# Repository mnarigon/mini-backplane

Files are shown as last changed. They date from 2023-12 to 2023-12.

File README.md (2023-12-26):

## A 4-slot S-100 bus mini-backplane with power supply chassis.

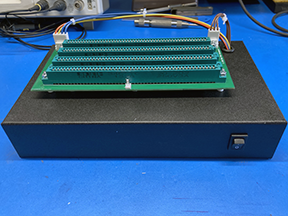
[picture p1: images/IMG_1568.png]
completed chassis


#### Description

This is a 4-slot S-100 bus mini-backplane with power supply chassis.

It is intended for someone interested in building and running S-100 bus cards, possibly as a first project or for use on a test bench.

Features:
- 4 slots.
- Chassis is designed for three Mean Well switching power supplies to provide 8V, 16V, and -16V in one unit. The maximum 8V current is 10 amps.
- Jumpers to ground for S-100 pins 20, 53, and 70. Some pre-IEEE-696 cards use these pins for signals where IEEE-696 defines these pins as grounds.
- Connector for a reset switch.

#### Mini-backplane Design Files

The mini-backplane design files in KiCad 7 are in the kicad directory.

The generated mini-backplane Gerber and drill files are in the file mini-backplane-gerbers.zip.

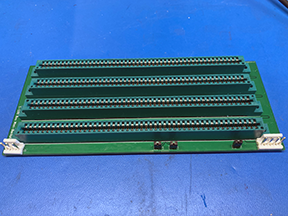
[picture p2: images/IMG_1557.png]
mini-backplane board


#### Chassis Design Files

The bill of materials is in the bom directory.

There is a poorly-executed layout drawing for the chassis holes in the chassis directory.

At maximum output power the power supplies will dissipate ~10W. A simple thermal
analysis indicated that cooling would be OK without any holes in the chassis.
However, I have a friend with a CNC mill who was willing mill the chassis, so I
added the cooling slots as shown on the drawing.

#### Chassis Assembly Notes

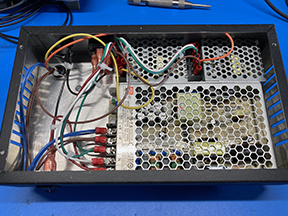
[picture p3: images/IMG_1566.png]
chassis wiring


The chassis is tight, if I built this again I would select a slightly larger chassis. The height is OK, but a chassis that was an inch or two longer and wider would make it easier to wire and install the power supplies.

The power switch didn’t sit tight in its mounting hole. The chassis wall thickness is 0.040 inch and the switch might have been designed for a thicker walled chassis. I used some hot glue on the switch to keep it from moving.

Wait to install the IEC power connector until you have the power supplies installed. You will need clearance to install the 16V and -16V power supplies.

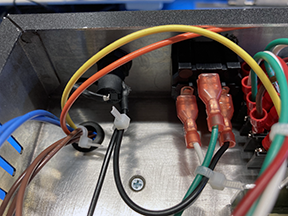
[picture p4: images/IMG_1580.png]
IEC power connector


#### Assembly Steps

1. Make up the wires that will go to the IEC power connector quick connect terminals.
1. Make up the wires that go from the backplane connectors to the power supplies.
1. Wire the 16V and -16V power supplies to each other and the backplane cables.
1. Wire the fuse holder and power switch.
1. Epoxy two of the 4-40 by 1 inch flat-headed screws that hold the mini-backplane to the chassis. They will be hidden by the installed power supplies.
1. Mount the 8V supply and wire to the switch and IEC connector wires.
1. Mount the 16V and -16V supplies. They will fit in but it will take some persuasion.
1. Install the IEC power connector. Finish installing all the wiring.
1. Complete by mounting the backplane on the chassis.

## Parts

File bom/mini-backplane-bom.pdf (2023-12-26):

Mini-Backplane BOM

Designator | Part | Value | Footprint | Manufacturer | Quantity | Digikey Part Number | Unit Price | Total
J1 | Header, Male Pins | | AMP_640445-4 | | 1 | A1972-ND | $0.27 | $0.27
J2 | Header, Male Pins | | AMP_640445-3 | | 1 | A19890-ND | $0.26 | $0.26
J3 | Header, Male Pins | | AMP_640454-2 | | 1 | A19423-ND | $0.15 | $0.15
JP1-JP3 | Pin Header | | PinHeader_01x02_P2.54mm | | 3 | 609-3507-ND | $0.16 | $0.48
| Mating Connector for J1 | | | | 1 | A24113-ND | $0.25 | $0.25
| Mating Connector for J2 | | | | 1 | A24112-ND | $0.20 | $0.20
| Mating Connector for J3 | | | | 1 | A99613-ND | $0.15 | $0.15
| Contacts for J1, J2 | | | | 7 | A31396-ND | $0.35 | $2.45
| Contacts for J3 | | | | 2 | A100453CT-ND | $0.10 | $0.20
| Shunts for JP1-JP3 | | | | 3 | S9000-ND | $0.10 | $0.30
P1-P4 | Card Edge Connector | | EDAC_346-100-520-202 | | 4 | EDC346102-ND or ESA50DRSH-S288-ND | $15.48 | $61.92
| Chassis | | 10*6*2in (L*W*H) | Hammond 1444-16 | 1 | HM264-ND | $20.48 | $20.48
| Cover | | 10*6in (L*W*H) | Hammond 1434-16 | 1 | HM280-ND | $11.00 | $11.00
| 8V Power Supply | | 159*97*30mm (L*W*H) | Mean Well RSP 75-7.5 | 1 | 1866-4289-ND | $36.93 | $36.93
| +16V and -16V Power Supplies | | 62.5*51*28mm (L*W*H) | Mean Well RS-15-15 | 2 | 1866-4129-ND | $10.86 | $21.72
| Fuse Holder 10 A 250V 1 Circuit Cartridge Panel Mount | | | Wurth | 1 | 732-11380-ND | $1.86 | $1.86
| Fuse 1.25A 250V 5x20mm Slo-blow | | | Bel Fuse | 1 | 507-1247-ND | $0.25 | $0.25
| Rocker Switch SPST 10A (AC) 125 V Panel Mount, Snap-In | | | E-Switch | 1 | EG5617-ND | $0.66 | $0.66
| Power Entry, IEC Appliance, 10A | | | DIT | 1 | 4761-DAC-12F-ND | $0.73 | $0.73
| Grommet, 0.375in, Rubber, Black | | | Keystone Electronics | 1 | 36-745-ND | $0.27 | $0.27
| Spade Connector, 18-22AWG, M3 (for +8V PS) | | | | 10 | A135212-ND | $0.45 | $4.50
| Spade Connector, 18-22AWG, M3 (for +/-16V PS) | | | | 14 | 298-20471-1-ND | $0.42 | $5.87
| Quick-Connect Connector, 4.7mm | | | | 5 | A27806CT-ND | $0.26 | $1.30
| Bumper Cylindrical, Recessed Center 0.500" Dia | | | Keystone Electronics | 4 | 36-720-ND | $0.32 | $1.28
| Round Spacer #4 Nylon, 3/8in | | | Bivar, Inc. | 4 | 492-1091-ND | $0.10 | $0.40
| 6-32xL3/8 in Self-Tapping Sheet Metal Screws (for cover) | | | Bolt Depot | 4
| 4-40xL1/2 in Pan Head Machine Screw (for bumper feet) | | | Bolt Depot | 4
| #4 washer (for bumper feet) | | | Bolt Depot | 4
| 4-40 nut (for bumper feet, double to lock) | | | Bolt Depot | 8
| 4-40xL1 in Flat Head Machine Screw (for standoffs) | | | Bolt Depot | 4
| 4-40 K-nut (for standoffs) | | | Bolt Depot | 4
| M3xL5 Hardware (for PS mount) | | | Bolt Depot | 6
| M3 washer (for PS mount) | | | Bolt Depot | 6
| M3 lock washer (for PS mount) | | | Bolt Depot | 6
| Black/White/Green/Red/Brown/Blue/Orange/Yellow 18-Gauge Wire
Total | | | | | | | | $173.88

1

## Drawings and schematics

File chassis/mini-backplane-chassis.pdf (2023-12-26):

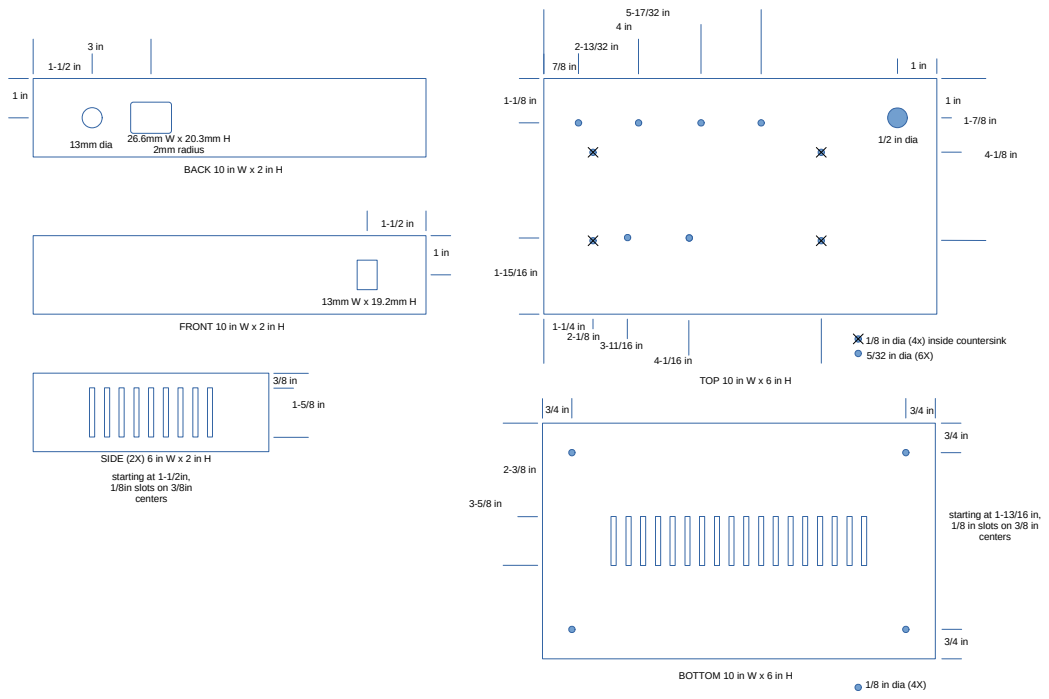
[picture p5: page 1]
26.6mm W x 20.3mm H 2mm radius 13mm dia; 1/2 in dia; 1/8 in dia (4X)

BACK 10 in W x 2 in H

FRONT 10 in W x 2 in H

1/8 in dia (4x) inside countersink
5/32 in dia (6X)

TOP 10 in W x 6 in H

SIDE (2X) 6 in W x 2 in H
starting at 1-1/2in,
1/8in slots on 3/8in
centers

starting at 1-13/16 in,
1/8 in slots on 3/8 in

BOTTOM 10 in W x 6 in H

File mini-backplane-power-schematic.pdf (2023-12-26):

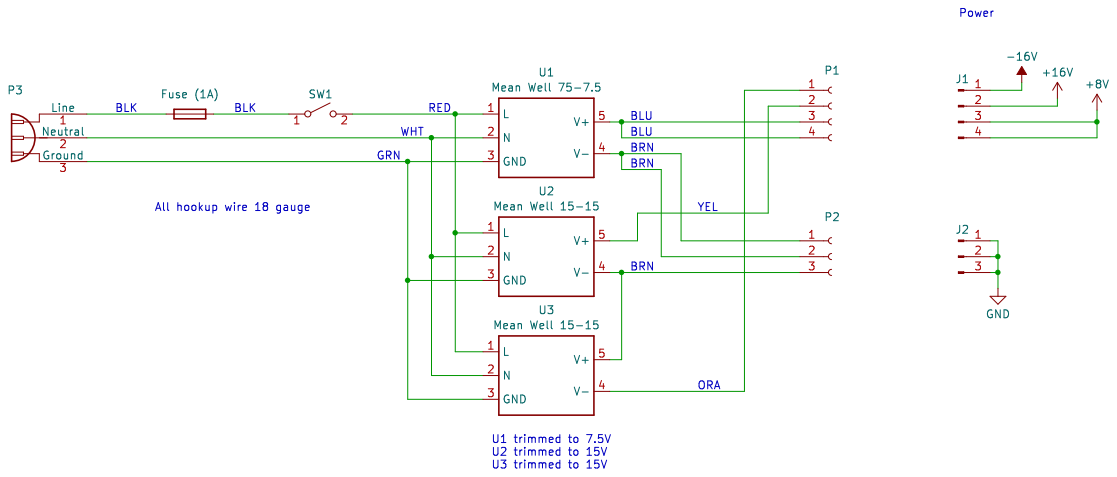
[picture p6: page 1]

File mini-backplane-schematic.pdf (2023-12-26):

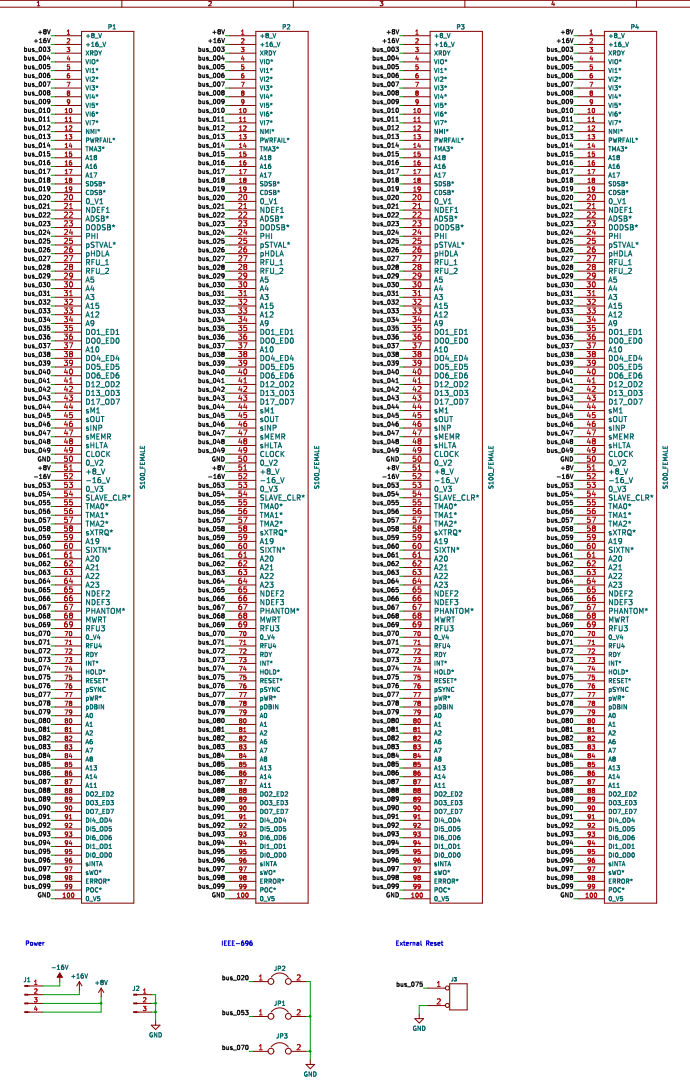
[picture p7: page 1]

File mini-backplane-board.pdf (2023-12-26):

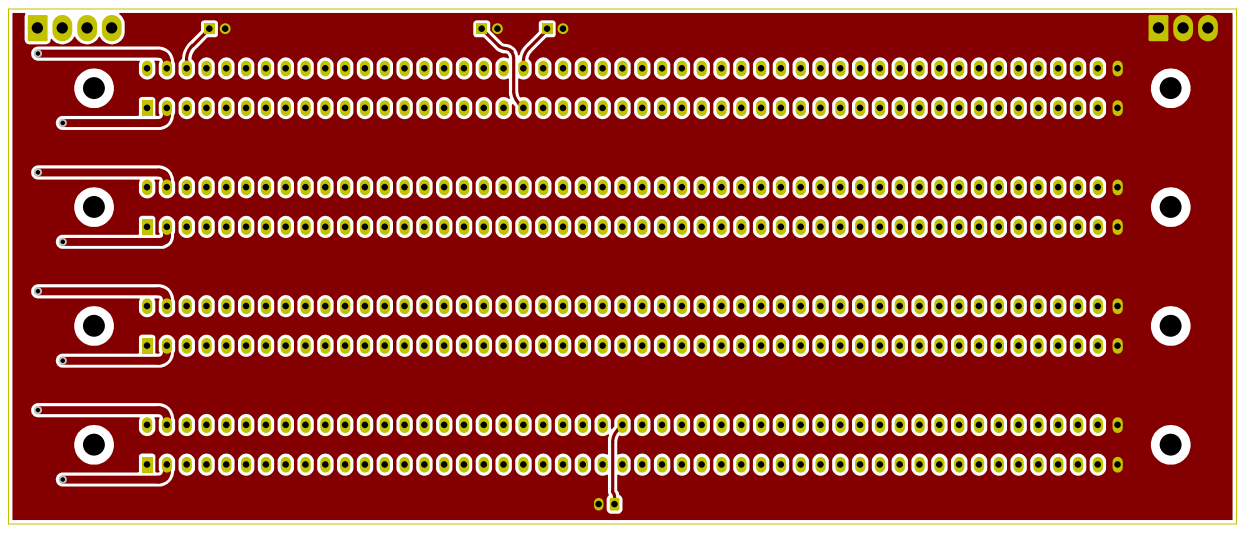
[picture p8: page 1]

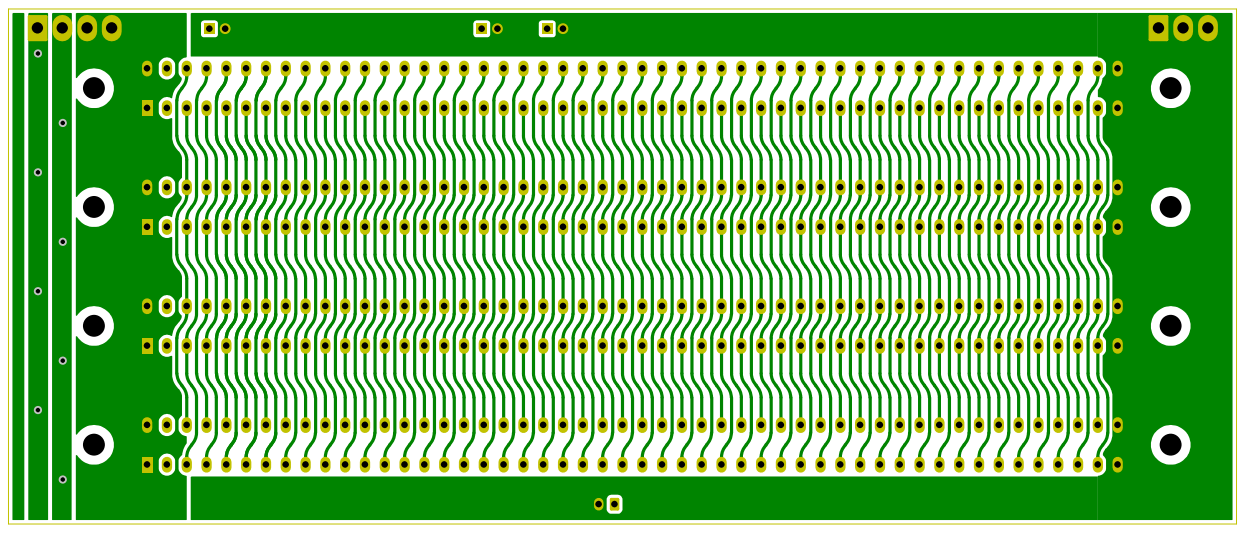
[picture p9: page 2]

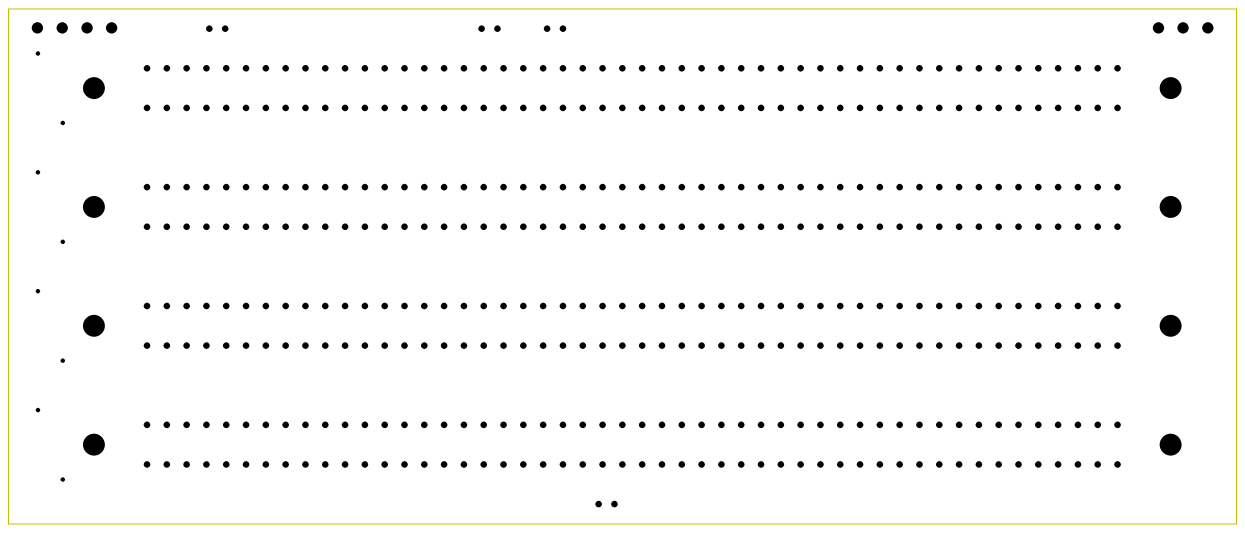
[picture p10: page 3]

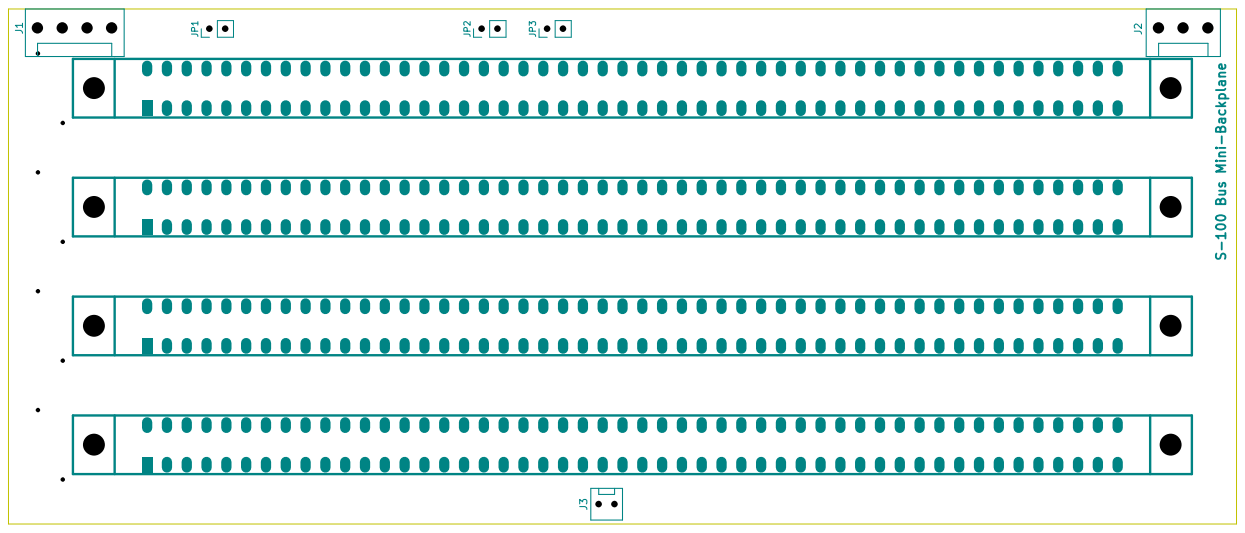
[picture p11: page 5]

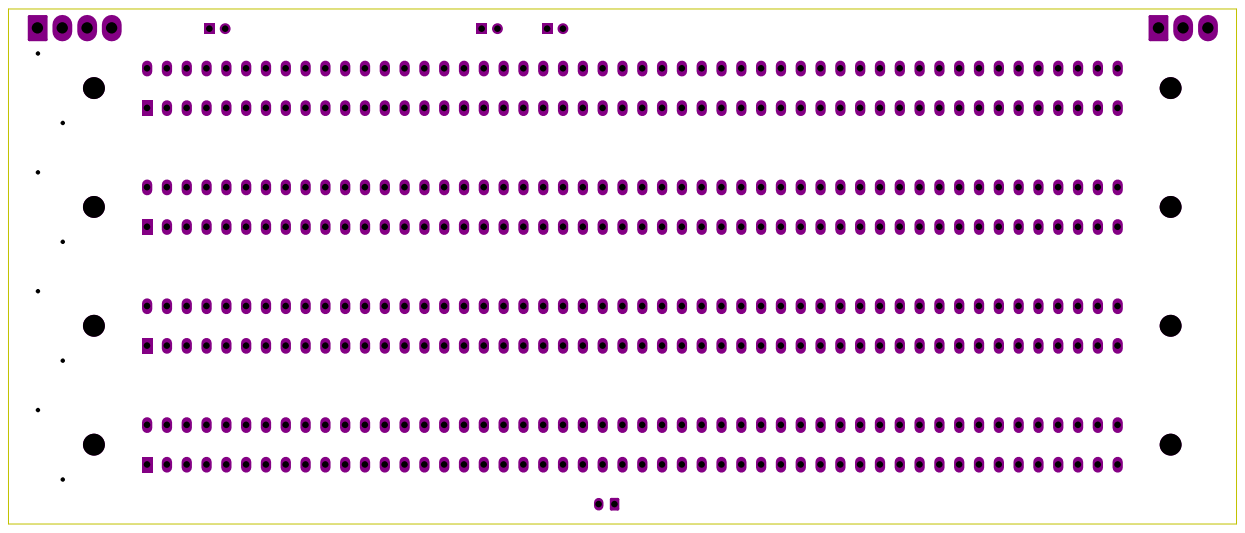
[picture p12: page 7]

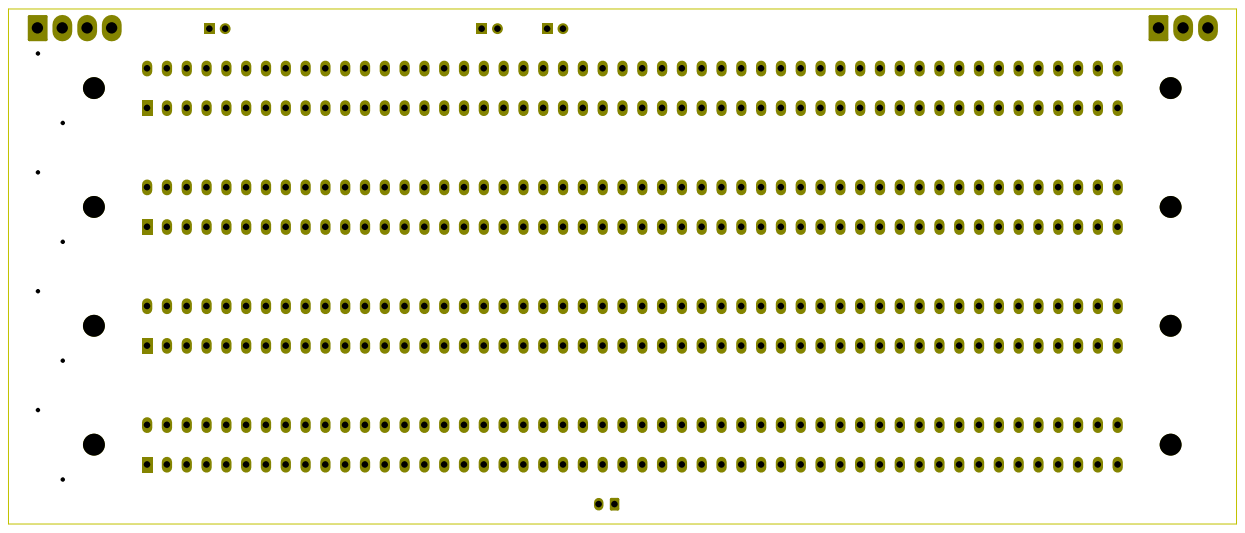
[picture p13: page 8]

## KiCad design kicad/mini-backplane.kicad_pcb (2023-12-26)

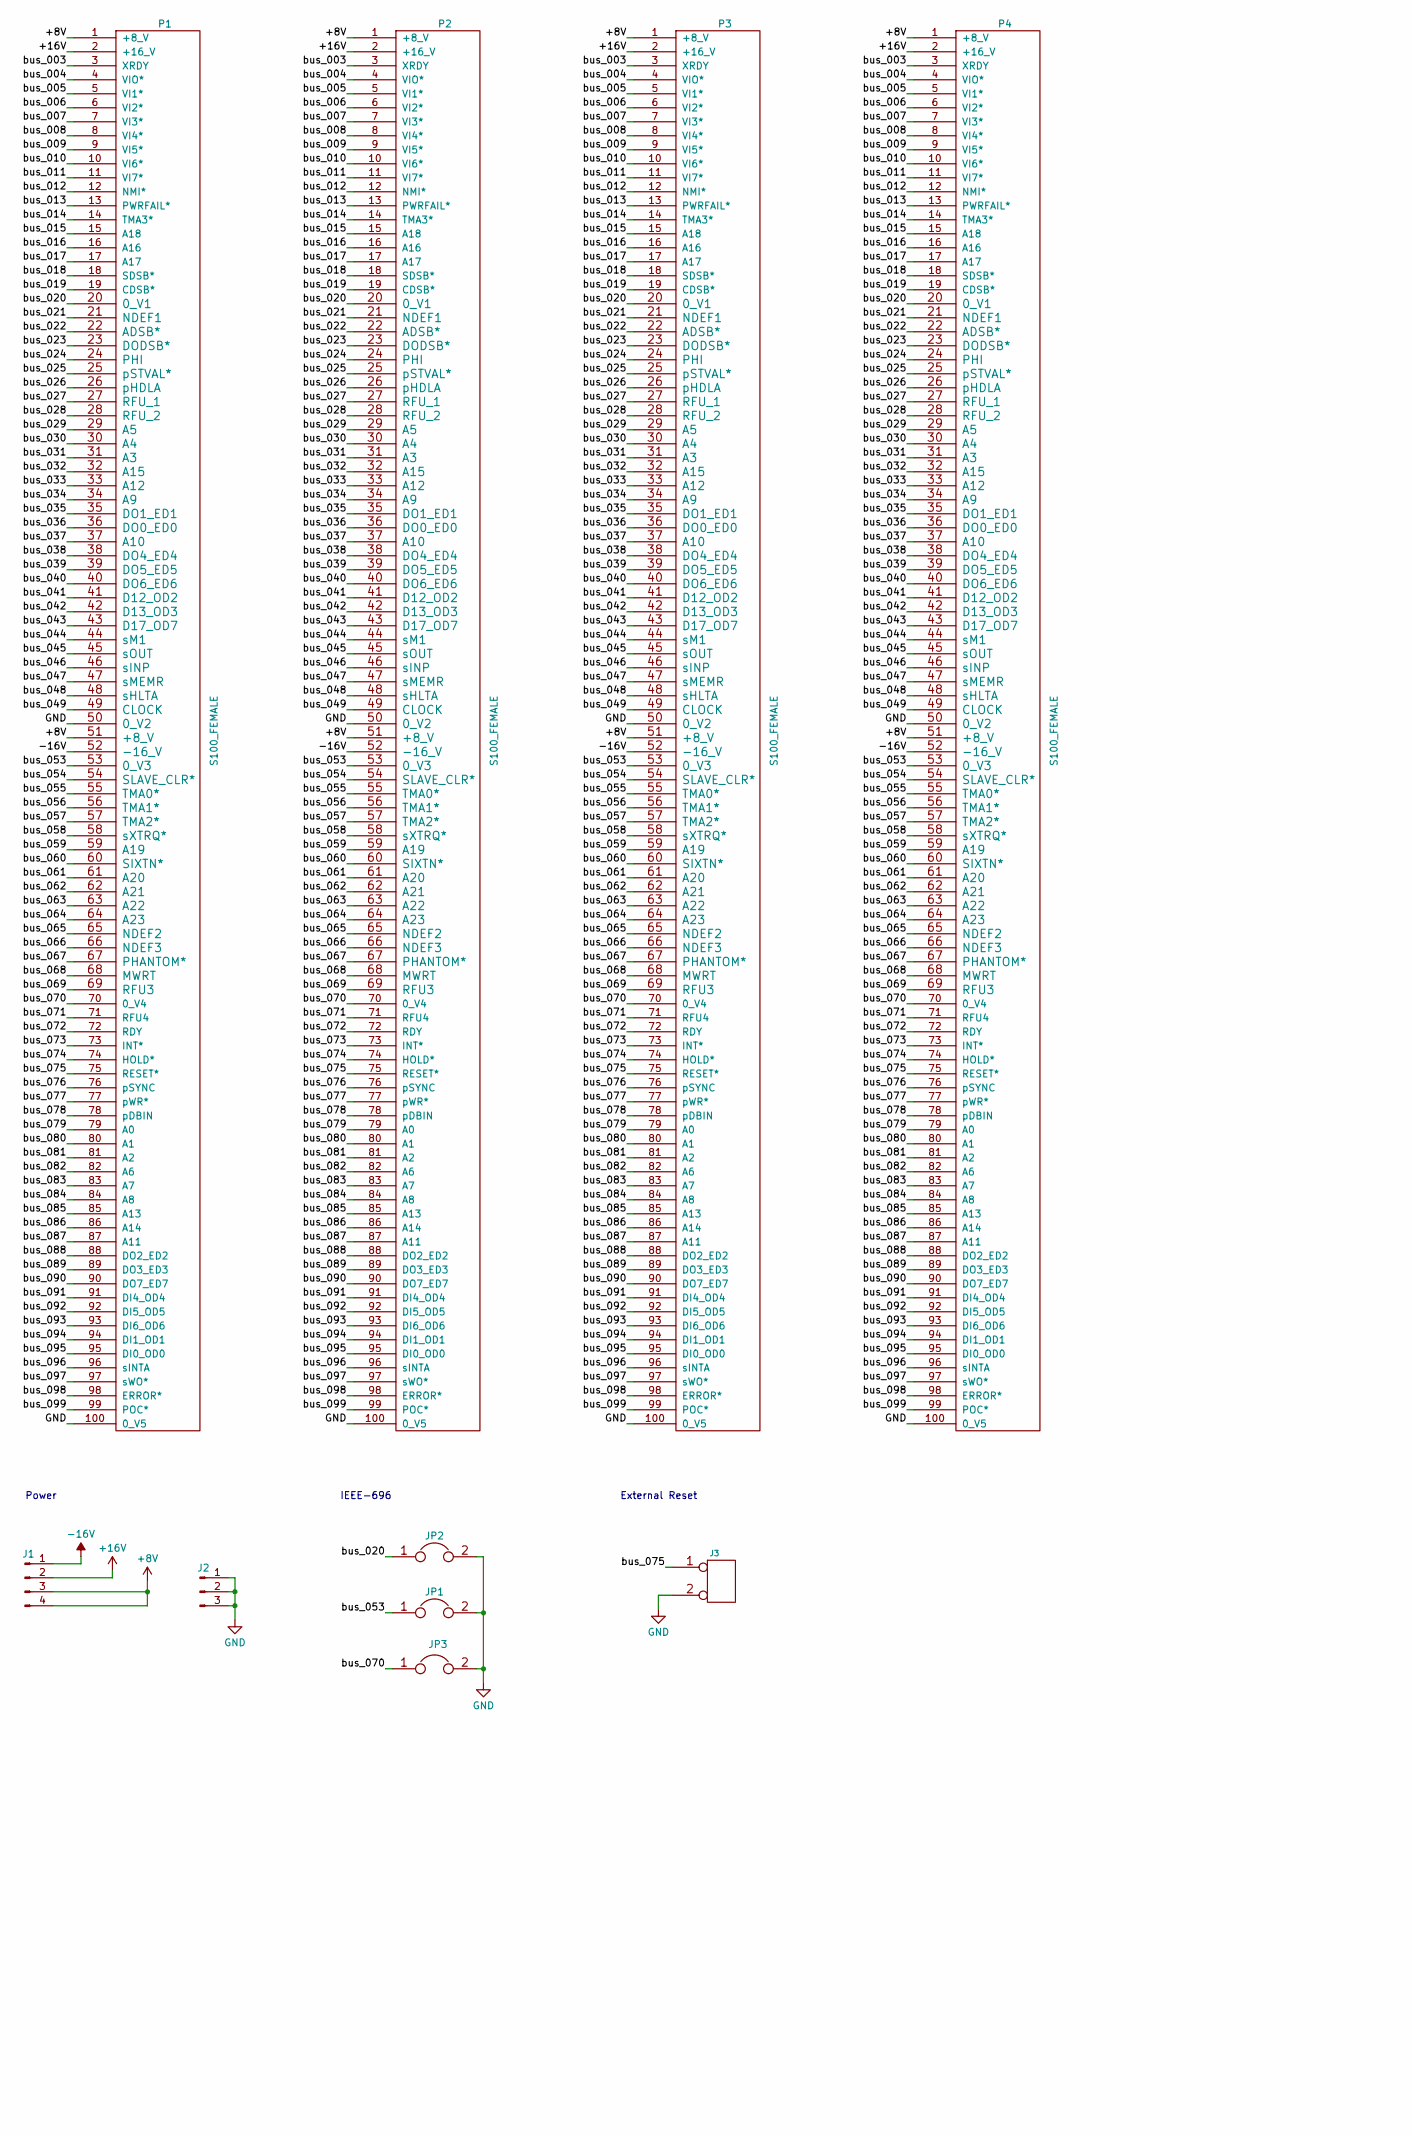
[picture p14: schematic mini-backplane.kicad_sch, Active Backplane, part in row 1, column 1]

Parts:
J1: Conn_01x04_Pin; AMP_640445-4
J2: Conn_01x03_Pin; AMP_640445-3
J3: Conn_01x02_Pin; AMP_640454-2
JP1, JP2, JP3: JUMPER; PinHeader_01x02_P2.54mm
P1, P2, P3, P4: S100_FEMALE; EDAC_346-100-520-202

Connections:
+8V: J1.3, J1.4, P1.1 (+8_V), P1.51 (+8_V), P2.1 (+8_V), P2.51 (+8_V), P3.1 (+8_V), P3.51 (+8_V), P4.1 (+8_V), P4.51 (+8_V)
+16V: J1.2, P1.2 (+16_V), P2.2 (+16_V), P3.2 (+16_V), P4.2 (+16_V)
-16V: J1.1, P1.52 (-16_V), P2.52 (-16_V), P3.52 (-16_V), P4.52 (-16_V)
/bus_003: P1.3 (XRDY), P2.3 (XRDY), P3.3 (XRDY), P4.3 (XRDY)
/bus_004: P1.4 (VIO*), P2.4 (VIO*), P3.4 (VIO*), P4.4 (VIO*)
/bus_005: P1.5 (VI1*), P2.5 (VI1*), P3.5 (VI1*), P4.5 (VI1*)
/bus_006: P1.6 (VI2*), P2.6 (VI2*), P3.6 (VI2*), P4.6 (VI2*)
/bus_007: P1.7 (VI3*), P2.7 (VI3*), P3.7 (VI3*), P4.7 (VI3*)
/bus_008: P1.8 (VI4*), P2.8 (VI4*), P3.8 (VI4*), P4.8 (VI4*)
/bus_009: P1.9 (VI5*), P2.9 (VI5*), P3.9 (VI5*), P4.9 (VI5*)
/bus_010: P1.10 (VI6*), P2.10 (VI6*), P3.10 (VI6*), P4.10 (VI6*)
/bus_011: P1.11 (VI7*), P2.11 (VI7*), P3.11 (VI7*), P4.11 (VI7*)
/bus_012: P1.12 (NMI*), P2.12 (NMI*), P3.12 (NMI*), P4.12 (NMI*)
/bus_013: P1.13 (PWRFAIL*), P2.13 (PWRFAIL*), P3.13 (PWRFAIL*), P4.13 (PWRFAIL*)
/bus_014: P1.14 (TMA3*), P2.14 (TMA3*), P3.14 (TMA3*), P4.14 (TMA3*)
/bus_015: P1.15 (A18), P2.15 (A18), P3.15 (A18), P4.15 (A18)
/bus_016: P1.16 (A16), P2.16 (A16), P3.16 (A16), P4.16 (A16)
/bus_017: P1.17 (A17), P2.17 (A17), P3.17 (A17), P4.17 (A17)
/bus_018: P1.18 (SDSB*), P2.18 (SDSB*), P3.18 (SDSB*), P4.18 (SDSB*)
/bus_019: P1.19 (CDSB*), P2.19 (CDSB*), P3.19 (CDSB*), P4.19 (CDSB*)
/bus_020: JP2.1, P1.20 (0_V1), P2.20 (0_V1), P3.20 (0_V1), P4.20 (0_V1)
/bus_021: P1.21 (NDEF1), P2.21 (NDEF1), P3.21 (NDEF1), P4.21 (NDEF1)
/bus_022: P1.22 (ADSB*), P2.22 (ADSB*), P3.22 (ADSB*), P4.22 (ADSB*)
/bus_023: P1.23 (DODSB*), P2.23 (DODSB*), P3.23 (DODSB*), P4.23 (DODSB*)
/bus_024: P1.24 (PHI), P2.24 (PHI), P3.24 (PHI), P4.24 (PHI)
/bus_025: P1.25 (pSTVAL*), P2.25 (pSTVAL*), P3.25 (pSTVAL*), P4.25 (pSTVAL*)
/bus_026: P1.26 (pHDLA), P2.26 (pHDLA), P3.26 (pHDLA), P4.26 (pHDLA)
/bus_027: P1.27 (RFU_1), P2.27 (RFU_1), P3.27 (RFU_1), P4.27 (RFU_1)
/bus_028: P1.28 (RFU_2), P2.28 (RFU_2), P3.28 (RFU_2), P4.28 (RFU_2)
/bus_029: P1.29 (A5), P2.29 (A5), P3.29 (A5), P4.29 (A5)
/bus_030: P1.30 (A4), P2.30 (A4), P3.30 (A4), P4.30 (A4)
/bus_031: P1.31 (A3), P2.31 (A3), P3.31 (A3), P4.31 (A3)
/bus_032: P1.32 (A15), P2.32 (A15), P3.32 (A15), P4.32 (A15)
/bus_033: P1.33 (A12), P2.33 (A12), P3.33 (A12), P4.33 (A12)
/bus_034: P1.34 (A9), P2.34 (A9), P3.34 (A9), P4.34 (A9)
/bus_035: P1.35 (DO1_ED1), P2.35 (DO1_ED1), P3.35 (DO1_ED1), P4.35 (DO1_ED1)
/bus_036: P1.36 (DO0_ED0), P2.36 (DO0_ED0), P3.36 (DO0_ED0), P4.36 (DO0_ED0)
/bus_037: P1.37 (A10), P2.37 (A10), P3.37 (A10), P4.37 (A10)
/bus_038: P1.38 (DO4_ED4), P2.38 (DO4_ED4), P3.38 (DO4_ED4), P4.38 (DO4_ED4)
/bus_039: P1.39 (DO5_ED5), P2.39 (DO5_ED5), P3.39 (DO5_ED5), P4.39 (DO5_ED5)
/bus_040: P1.40 (DO6_ED6), P2.40 (DO6_ED6), P3.40 (DO6_ED6), P4.40 (DO6_ED6)
/bus_041: P1.41 (D12_OD2), P2.41 (D12_OD2), P3.41 (D12_OD2), P4.41 (D12_OD2)
/bus_042: P1.42 (D13_OD3), P2.42 (D13_OD3), P3.42 (D13_OD3), P4.42 (D13_OD3)
/bus_043: P1.43 (D17_OD7), P2.43 (D17_OD7), P3.43 (D17_OD7), P4.43 (D17_OD7)
/bus_044: P1.44 (sM1), P2.44 (sM1), P3.44 (sM1), P4.44 (sM1)
/bus_045: P1.45 (sOUT), P2.45 (sOUT), P3.45 (sOUT), P4.45 (sOUT)
/bus_046: P1.46 (sINP), P2.46 (sINP), P3.46 (sINP), P4.46 (sINP)
/bus_047: P1.47 (sMEMR), P2.47 (sMEMR), P3.47 (sMEMR), P4.47 (sMEMR)
/bus_048: P1.48 (sHLTA), P2.48 (sHLTA), P3.48 (sHLTA), P4.48 (sHLTA)
/bus_049: P1.49 (CLOCK), P2.49 (CLOCK), P3.49 (CLOCK), P4.49 (CLOCK)
/bus_053: JP1.1, P1.53 (0_V3), P2.53 (0_V3), P3.53 (0_V3), P4.53 (0_V3)
/bus_054: P1.54 (SLAVE_CLR*), P2.54 (SLAVE_CLR*), P3.54 (SLAVE_CLR*), P4.54 (SLAVE_CLR*)
/bus_055: P1.55 (TMA0*), P2.55 (TMA0*), P3.55 (TMA0*), P4.55 (TMA0*)
/bus_056: P1.56 (TMA1*), P2.56 (TMA1*), P3.56 (TMA1*), P4.56 (TMA1*)
/bus_057: P1.57 (TMA2*), P2.57 (TMA2*), P3.57 (TMA2*), P4.57 (TMA2*)
/bus_058: P1.58 (sXTRQ*), P2.58 (sXTRQ*), P3.58 (sXTRQ*), P4.58 (sXTRQ*)
/bus_059: P1.59 (A19), P2.59 (A19), P3.59 (A19), P4.59 (A19)
/bus_060: P1.60 (SIXTN*), P2.60 (SIXTN*), P3.60 (SIXTN*), P4.60 (SIXTN*)
/bus_061: P1.61 (A20), P2.61 (A20), P3.61 (A20), P4.61 (A20)
/bus_062: P1.62 (A21), P2.62 (A21), P3.62 (A21), P4.62 (A21)
/bus_063: P1.63 (A22), P2.63 (A22), P3.63 (A22), P4.63 (A22)
/bus_064: P1.64 (A23), P2.64 (A23), P3.64 (A23), P4.64 (A23)
/bus_065: P1.65 (NDEF2), P2.65 (NDEF2), P3.65 (NDEF2), P4.65 (NDEF2)
/bus_066: P1.66 (NDEF3), P2.66 (NDEF3), P3.66 (NDEF3), P4.66 (NDEF3)
/bus_067: P1.67 (PHANTOM*), P2.67 (PHANTOM*), P3.67 (PHANTOM*), P4.67 (PHANTOM*)
/bus_068: P1.68 (MWRT), P2.68 (MWRT), P3.68 (MWRT), P4.68 (MWRT)
/bus_069: P1.69 (RFU3), P2.69 (RFU3), P3.69 (RFU3), P4.69 (RFU3)
/bus_070: JP3.1, P1.70 (0_V4), P2.70 (0_V4), P3.70 (0_V4), P4.70 (0_V4)
/bus_071: P1.71 (RFU4), P2.71 (RFU4), P3.71 (RFU4), P4.71 (RFU4)
/bus_072: P1.72 (RDY), P2.72 (RDY), P3.72 (RDY), P4.72 (RDY)
/bus_073: P1.73 (INT*), P2.73 (INT*), P3.73 (INT*), P4.73 (INT*)
/bus_074: P1.74 (HOLD*), P2.74 (HOLD*), P3.74 (HOLD*), P4.74 (HOLD*)
/bus_075: J3.1, P1.75 (RESET*), P2.75 (RESET*), P3.75 (RESET*), P4.75 (RESET*)
/bus_076: P1.76 (pSYNC), P2.76 (pSYNC), P3.76 (pSYNC), P4.76 (pSYNC)
/bus_077: P1.77 (pWR*), P2.77 (pWR*), P3.77 (pWR*), P4.77 (pWR*)
/bus_078: P1.78 (pDBIN), P2.78 (pDBIN), P3.78 (pDBIN), P4.78 (pDBIN)
/bus_079: P1.79 (A0), P2.79 (A0), P3.79 (A0), P4.79 (A0)
/bus_080: P1.80 (A1), P2.80 (A1), P3.80 (A1), P4.80 (A1)
/bus_081: P1.81 (A2), P2.81 (A2), P3.81 (A2), P4.81 (A2)
/bus_082: P1.82 (A6), P2.82 (A6), P3.82 (A6), P4.82 (A6)
/bus_083: P1.83 (A7), P2.83 (A7), P3.83 (A7), P4.83 (A7)
/bus_084: P1.84 (A8), P2.84 (A8), P3.84 (A8), P4.84 (A8)
/bus_085: P1.85 (A13), P2.85 (A13), P3.85 (A13), P4.85 (A13)
/bus_086: P1.86 (A14), P2.86 (A14), P3.86 (A14), P4.86 (A14)
/bus_087: P1.87 (A11), P2.87 (A11), P3.87 (A11), P4.87 (A11)
/bus_088: P1.88 (DO2_ED2), P2.88 (DO2_ED2), P3.88 (DO2_ED2), P4.88 (DO2_ED2)
/bus_089: P1.89 (DO3_ED3), P2.89 (DO3_ED3), P3.89 (DO3_ED3), P4.89 (DO3_ED3)
/bus_090: P1.90 (DO7_ED7), P2.90 (DO7_ED7), P3.90 (DO7_ED7), P4.90 (DO7_ED7)
/bus_091: P1.91 (DI4_OD4), P2.91 (DI4_OD4), P3.91 (DI4_OD4), P4.91 (DI4_OD4)
/bus_092: P1.92 (DI5_OD5), P2.92 (DI5_OD5), P3.92 (DI5_OD5), P4.92 (DI5_OD5)
/bus_093: P1.93 (DI6_OD6), P2.93 (DI6_OD6), P3.93 (DI6_OD6), P4.93 (DI6_OD6)
/bus_094: P1.94 (DI1_OD1), P2.94 (DI1_OD1), P3.94 (DI1_OD1), P4.94 (DI1_OD1)
/bus_095: P1.95 (DI0_OD0), P2.95 (DI0_OD0), P3.95 (DI0_OD0), P4.95 (DI0_OD0)
/bus_096: P1.96 (sINTA), P2.96 (sINTA), P3.96 (sINTA), P4.96 (sINTA)
/bus_097: P1.97 (sWO*), P2.97 (sWO*), P3.97 (sWO*), P4.97 (sWO*)
/bus_098: P1.98 (ERROR*), P2.98 (ERROR*), P3.98 (ERROR*), P4.98 (ERROR*)
/bus_099: P1.99 (POC*), P2.99 (POC*), P3.99 (POC*), P4.99 (POC*)
GND: J2.1, J2.2, J2.3, J3.2 (PM), JP1.2, JP2.2, JP3.2, P1.50 (0_V2), P1.100 (0_V5), P2.50 (0_V2), P2.100 (0_V5), P3.50 (0_V2), P3.100 (0_V5), P4.50 (0_V2), P4.100 (0_V5)

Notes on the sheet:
Power
4-slot S-100 Bus Mini-Backplane
External Reset
IEEE-696

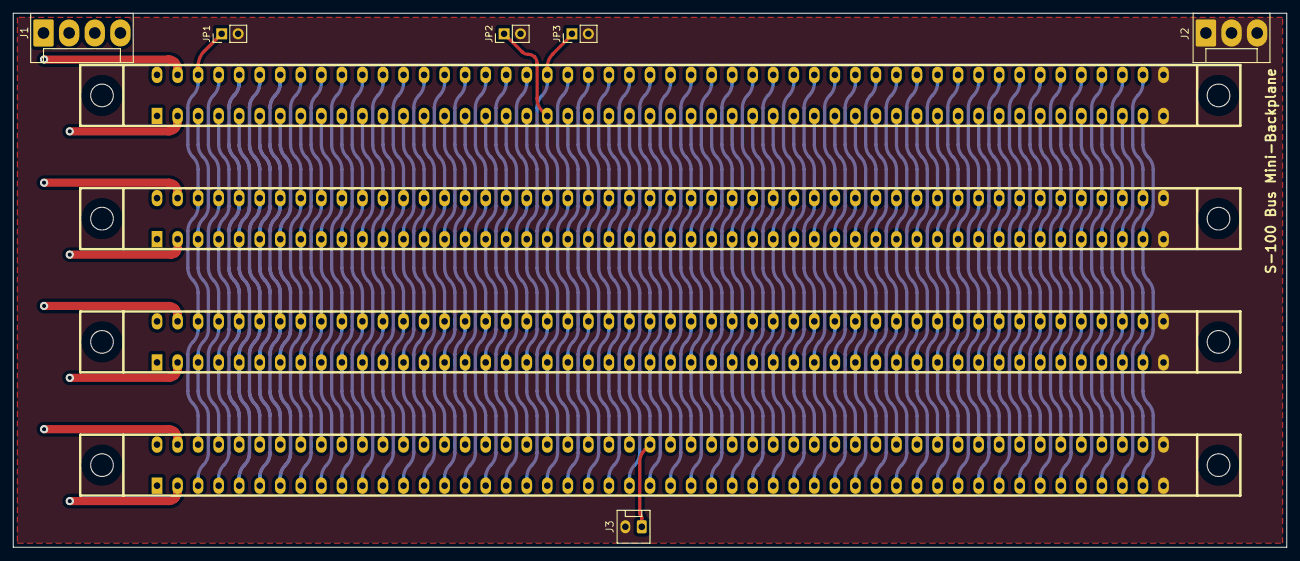
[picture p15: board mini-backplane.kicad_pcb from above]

Board: 2 copper layers, 196.8 x 82.6 mm, 10 parts (0 on the bottom side), 98 nets.
